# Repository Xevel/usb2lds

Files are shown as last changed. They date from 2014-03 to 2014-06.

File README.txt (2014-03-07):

USB2LDS
=======

2014 Nicolas "Xevel" Saugnier

Interface boards for the Neato LDS - the Lidar of the XV-11.
More on the Neato LDS : http://xv11hacking.wikispaces.com/LIDAR+Sensor

Boards:
- USB2LDS: USB interface for the Neato LDS, that also takes care of the motor control.
- Neato LDS Breakout Board (or NLDSBB): Simple breakout board that exposes the UART of the LDS, but takes care of the motor control.

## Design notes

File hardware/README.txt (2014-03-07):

USB2LDS hardware
================

USB2LDS versions:

v2.0 - 2014/01/12
- replaced FTDI with Atmega32u2
- added mosfet to allow PWM control of the motor
- added debug and hacking pads (/RST, /HWB, and the whole SPI bus)

v1.1 - 2014/01/11
- corrected LDS_TX/LDS_RX inversion on the connector
- The Lidar needs more power, use 3.3V regulator power instead of 3V3OUT from the FT232RL

V1.0 - 2014/01/09
- inital release

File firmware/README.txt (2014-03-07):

USB2LDS firmware
================

nlds - library to read data from the LDS (Firmware v2.4 and above) an extract the turn rate information.

nldsbb - firmware for the Neato LDS Breakout Board (ATtiny2313A)

usb2lds - firmware for the USB2LDS (ATmega32u2)

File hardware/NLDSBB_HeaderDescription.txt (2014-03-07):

Header of FTDI cable, interpreted from FTDI side.
GND: common ground
CTS: doit etre mise a GND par la cible
VCC: fournit 5V a la cible
TXD: envoi des char à la cible, doit être connecté au RXI de la cible
RXD: recoi les char de la cible, doit être connecté au TXO de la cible
RTS: output qui dit quand le FTDI est pret a recevoir. Laissé non connecté du coté cible si elle n'est pas capable de réguler son flux.

Header, from the board perspective:
GND : common ground
/MOT: connected to CTS, it can be controlled by the host to turn the motor ON (LOW or not connected) or OFF (HIGH)
VIN : power input, 5V
RXI : RX Input, goes directly to the LDS. This can be used by the host to send commands to the LDS, preferably when the motor is stopped.
TXO : TX output, comes directly from the LDS. That's where the info from the sensor will be avaialable for the host to read.
NC  : not connected

Only GND, VIN and TXO are necessary to read the info from the LDS.

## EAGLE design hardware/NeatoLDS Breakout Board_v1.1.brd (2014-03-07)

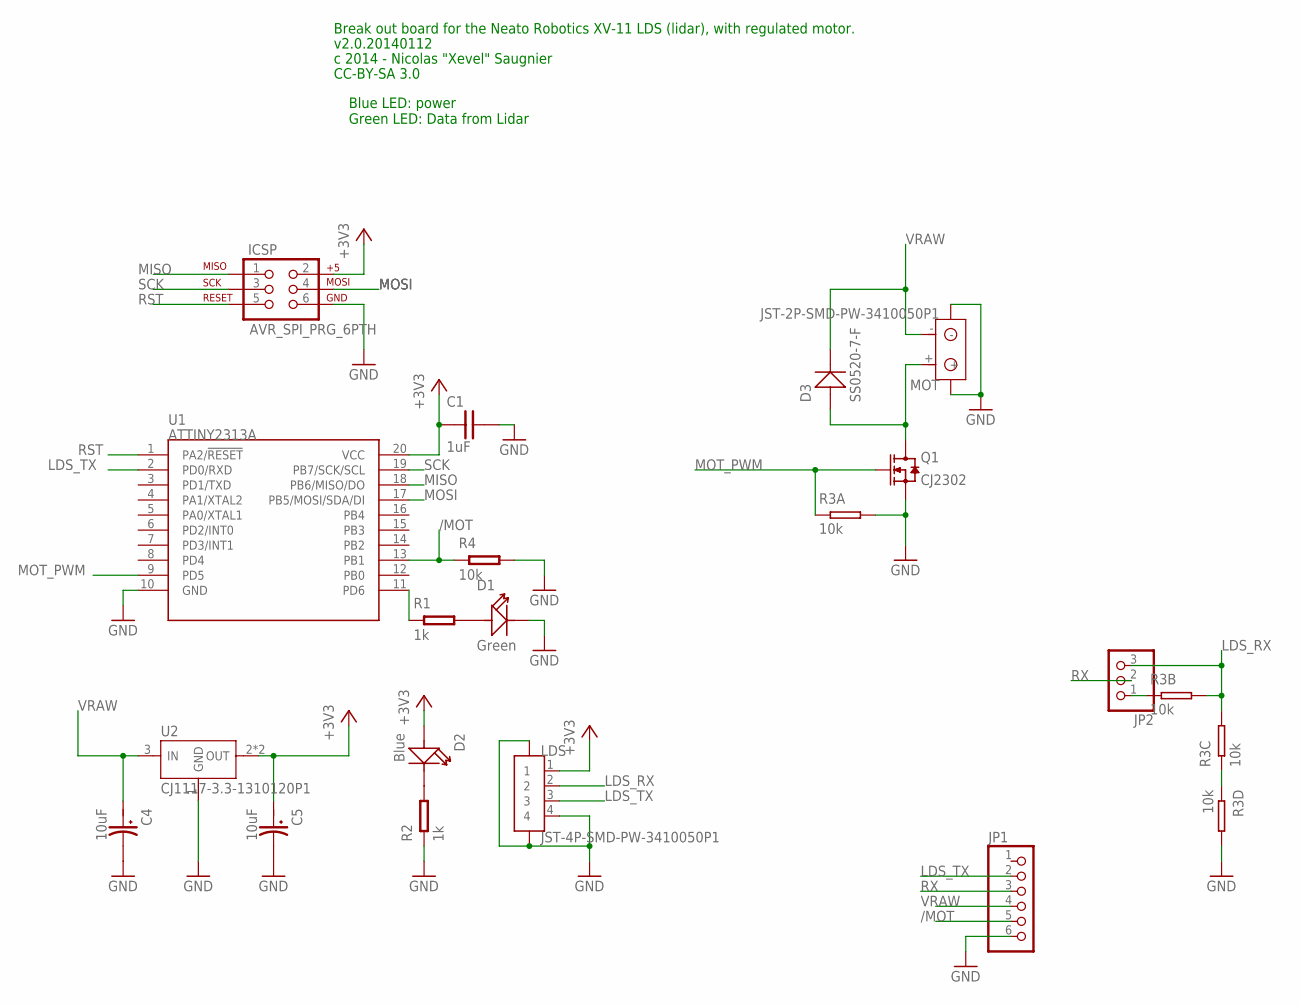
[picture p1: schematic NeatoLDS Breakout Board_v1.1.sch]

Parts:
C1: 1uF; C0603
C4, C5: 10uF; AVX-A
D1: Green; LED0603
D2: Blue; LED0603
D3: SS0520-7-F; SOD123
ICSP: AVR_SPI_PRG_6PTH; 2X3
JP1: PINHD-1X6; 1X06
JP2: PINHD-1X3; 1X03
LDS: JST-4P-SMD-PW-3410050P1; CON-4P-SMD-2.0-90D
MOT: JST-2P-SMD-PW-3410050P1; 2P-SMD-2.0-90D
Q1: CJ2302; SOT23
R1, R2: 1k; R0603
R3: 10k; R1206-8
R4: 10k; R0603
U1: ATTINY2313A; SOP20W
U2: CJ1117-3.3-1310120P1; SOT89

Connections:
+3V3: C1.1, C5.+ (1), D2.+, ICSP.2, LDS.1, U1.20 (VCC), U2.2 (OUT), U2.4 (OUT)
/MOT: JP1.5, R4.1, U1.13 (PB1)
GND: C1.2, C4.- (2), C5.- (2), D1.-, ICSP.6, JP1.6, LDS.4, LDS.5, LDS.6, MOT.3, MOT.4, Q1.2 (S), R2.1, R3.5 (2), R3.8 (2), R4.2, U1.10 (GND), U2.1 (GND)
LDS_RX: JP2.3, LDS.2, R3.6 (2), R3.7 (2)
LDS_TX: JP1.2, LDS.3, U1.2 (PD0/RXD)
MISO: ICSP.1, U1.18 (PB6/MISO/DO)
MOSI: ICSP.4, U1.17 (PB5/MOSI/SDA/DI)
MOT_PWM: Q1.1 (G), R3.1, U1.9 (PD5)
unnamed: R3.3 (1), R3.4 (1)
unnamed: JP2.1, R3.2 (1)
unnamed: R1.1, U1.11 (PD6)
unnamed: D3.+, MOT.+, Q1.3 (D)
unnamed: D1.+, R1.2
unnamed: D2.-, R2.2
RST: ICSP.5, U1.1 (PA2/!RESET)
RX: JP1.3, JP2.2
SCK: ICSP.3, U1.19 (PB7/SCK/SCL)
VRAW: C4.+ (1), D3.-, JP1.4, MOT.-, U2.3 (IN)

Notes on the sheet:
Blue LED: power Green LED: Data from Lidar
Break out board for the Neato Robotics XV-11 LDS (lidar), with regulated motor.
c 2014 - Nicolas "Xevel" Saugnier
CC-BY-SA 3.0
v2.0.20140112

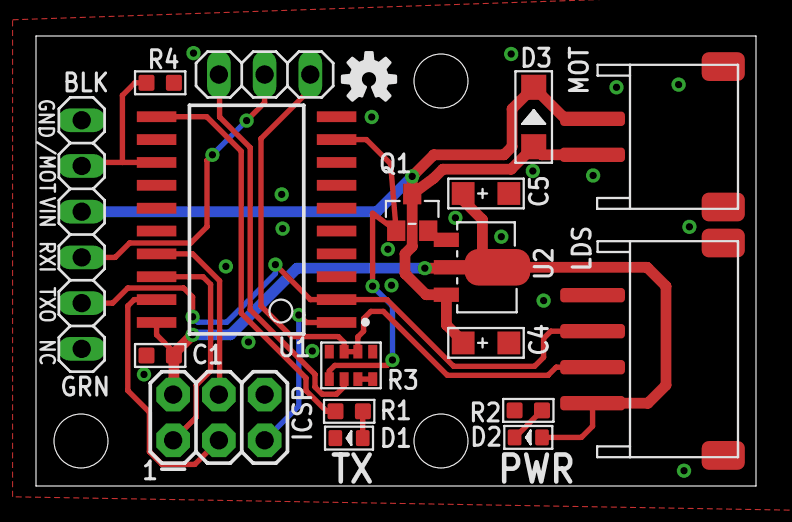
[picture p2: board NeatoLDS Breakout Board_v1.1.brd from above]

Board: 2 copper layers, 40.0 x 25.0 mm, 20 parts (1 on the bottom side), 18 nets.

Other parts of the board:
U$1, U$2: OSHW-LOGO-S

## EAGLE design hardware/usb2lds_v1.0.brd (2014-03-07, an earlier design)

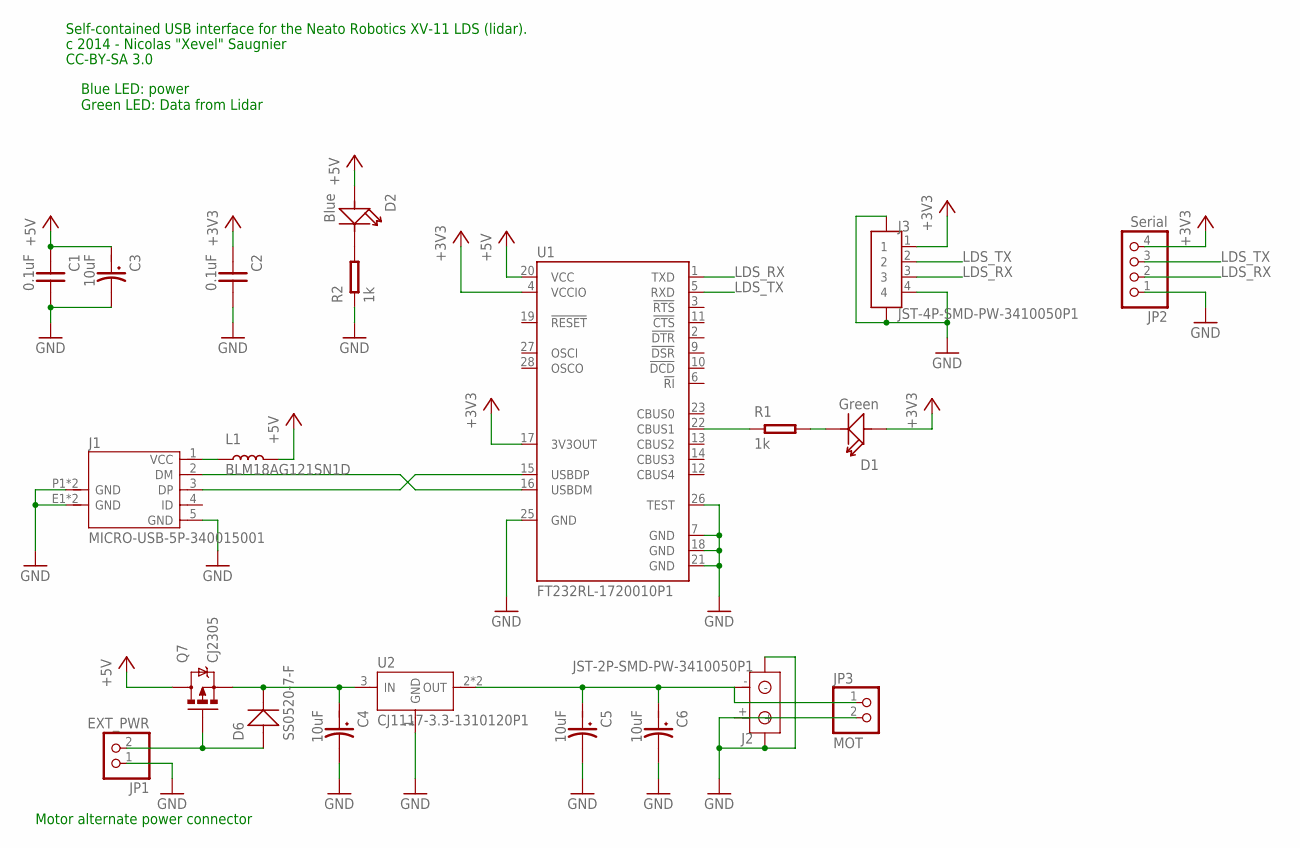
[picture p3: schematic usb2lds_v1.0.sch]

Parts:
C1, C2: 0.1uF; C0603
C3, C4, C5, C6: 10uF; AVX-A
D1: Green; LED0603
D2: Blue; LED0603
D6: SS0520-7-F; SOD123
J1: MICRO-USB-5P-340015001; B-SMD-5P
J2: JST-2P-SMD-PW-3410050P1; 2P-SMD-2.0-90D
J3: JST-4P-SMD-PW-3410050P1; CON-4P-SMD-2.0-90D
JP1: EXT_PWR; 1X02
JP2: Serial; 1X04
JP3: MOT; 1X02
L1: BLM18AG121SN1D; L0603
Q7: CJ2305; SOT-23-3_N/SSOT-3_N
R1, R2: 1k; R0603
U1: FT232RL-1720010P1; SSOP28
U2: CJ1117-3.3-1310120P1; SOT89

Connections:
+3V3: C2.1, D1.+, J3.1, JP2.4, U1.4 (VCCIO), U1.17 (3V3OUT)
+5V: C1.1, C3.+ (1), D2.+, L1.2, Q7.3 (D), U1.20 (VCC)
GND: C1.2, C2.2, C3.- (2), C4.- (2), C5.- (2), C6.- (2), J1.5 (GND), J1.E1 (GND), J1.E2 (GND), J1.P1 (GND), J1.P2 (GND), J2.3, J2.4, J2.+, J3.4, J3.5, J3.6, JP1.1, JP2.1, JP3.2, R2.1, U1.7 (GND), U1.18 (GND), U1.21 (GND), U1.25 (GND), U1.26 (TEST), U2.1 (GND)
LDS_RX: J3.3, JP2.2, U1.1 (TXD)
LDS_TX: J3.2, JP2.3, U1.5 (RXD)
unnamed: J1.2 (DM), U1.16 (USBDM)
unnamed: J1.3 (DP), U1.15 (USBDP)
unnamed: J1.1 (VCC), L1.1
unnamed: D1.-, R1.2
unnamed: D2.-, R2.2
unnamed: R1.1, U1.22 (CBUS1)
unnamed: C5.+ (1), C6.+ (1), J2.-, JP3.1, U2.2 (OUT), U2.4 (OUT)
unnamed: C4.+ (1), D6.-, Q7.2 (S), U2.3 (IN)
VUSB: D6.+, JP1.2, Q7.1 (G)

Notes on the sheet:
Blue LED: power Green LED: Data from Lidar
Self-contained USB interface for the Neato Robotics XV-11 LDS (lidar).
c 2014 - Nicolas "Xevel" Saugnier
CC-BY-SA 3.0
Motor alternate power connector

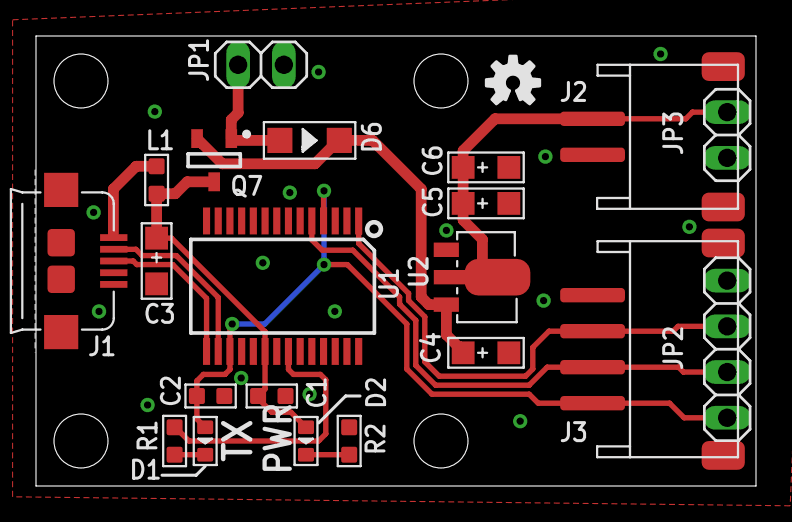
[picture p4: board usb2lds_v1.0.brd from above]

Board: 2 copper layers, 40.0 x 25.0 mm, 23 parts (1 on the bottom side), 14 nets.

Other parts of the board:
U$1, U$2: OSHW-LOGO-S

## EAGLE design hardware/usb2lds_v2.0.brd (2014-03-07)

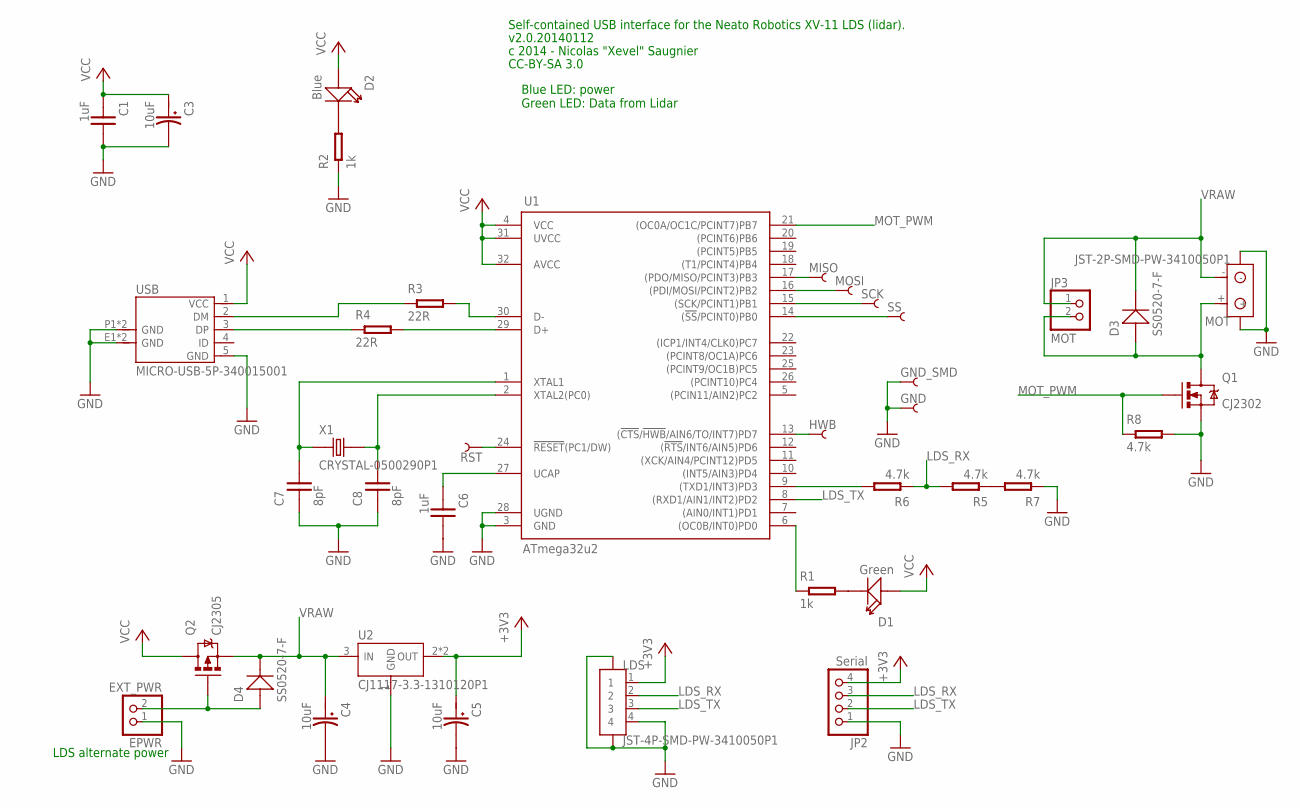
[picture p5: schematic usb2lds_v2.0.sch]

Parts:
C1, C6: 1uF; C0603
C3, C4, C5: 10uF; AVX-A
C7, C8: 8pF; C0603
D1: Green; LED0603
D2: Blue; LED0603
D3, D4: SS0520-7-F; SOD123
EPWR: EXT_PWR; 1X02
GND: PIN_SMD_2X2.5
GND_SMD: PIN_SMD_2X2.5
HWB: PIN_SMD_2X2.5
JP2: Serial; 1X04
JP3: MOT; 1X02
LDS: JST-4P-SMD-PW-3410050P1; CON-4P-SMD-2.0-90D
MISO: PIN_SMD_2X2.5
MOSI: PIN_SMD_2X2.5
MOT: JST-2P-SMD-PW-3410050P1; 2P-SMD-2.0-90D
Q1: CJ2302; SOT-23-3_N/SSOT-3_N
Q2: CJ2305; SOT-23-3_N/SSOT-3_N
R1, R2: 1k; R0603
R3, R4: 22R; R0603
R5, R6, R7, R8: 4.7k; R0603
RST: PIN_SMD_2X2.5
SCK: PIN_SMD_2X2.5
SS: PIN_SMD_2X2.5
U1: ATmega32u2; QFN-32_50P_L_MOD
U2: CJ1117-3.3-1310120P1; SOT89
USB: MICRO-USB-5P-340015001; B-SMD-5P
X1: CRYSTAL-0500290P1; 2P-SMD-5.0X3.2

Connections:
+3V3: C5.+ (1), JP2.4, LDS.1, U2.2 (OUT), U2.4 (OUT)
GND: C1.2, C3.- (2), C4.- (2), C5.- (2), C6.2, C7.1, C8.1, EPWR.1, GND.PIN, GND_SMD.PIN, JP2.1, LDS.4, LDS.5, LDS.6, MOT.3, MOT.4, Q1.2 (S), R2.1, R7.1, R8.2, U1.3 (GND), U1.28 (UGND), U2.1 (GND), USB.5 (GND), USB.E1 (GND), USB.E2 (GND), USB.P1 (GND), USB.P2 (GND)
HWB: HWB.PIN, U1.13 ((!CTS!/!HWB!/AIN6/TO/INT7)PD7)
LDS_RX: JP2.3, LDS.2, R5.2, R6.1
LDS_TX: JP2.2, LDS.3, U1.8 ((RXD1/AIN1/INT2)PD2)
MOT_PWM: Q1.1 (G), R8.1, U1.21 ((OC0A/OC1C/PCINT7)PB7)
unnamed: R6.2, U1.9 ((TXD1/INT3)PD3)
unnamed: R1.1, U1.6 ((OC0B/INT0)PD0)
unnamed: C6.1, U1.27 (UCAP)
unnamed: D3.+, JP3.2, MOT.+, Q1.3 (D)
unnamed: C8.2, U1.2 (XTAL2(PC0)), X1.2
unnamed: D1.-, R1.2
unnamed: D2.-, R2.2
unnamed: C7.2, U1.1 (XTAL1), X1.1
unnamed: R5.1, R7.2
unnamed: R3.2, U1.30 (D-)
unnamed: R4.2, U1.29 (D+)
unnamed: R3.1, USB.2 (DM)
unnamed: R4.1, USB.3 (DP)
unnamed: MISO.PIN, U1.17 ((PDO/MISO/PCINT3)PB3)
unnamed: MOSI.PIN, U1.16 ((PDI/MOSI/PCINT2)PB2)
unnamed: SCK.PIN, U1.15 ((SCK/PCINT1)PB1)
unnamed: SS.PIN, U1.14 ((!SS!/PCINT0)PB0)
RST: RST.PIN, U1.24 (!RESET!(PC1/DW))
VCC: C1.1, C3.+ (1), D1.+, D2.+, Q2.3 (D), U1.4 (VCC), U1.31 (UVCC), U1.32 (AVCC), USB.1 (VCC)
VRAW: C4.+ (1), D3.-, D4.-, JP3.1, MOT.-, Q2.2 (S), U2.3 (IN)
VUSB: D4.+, EPWR.2, Q2.1 (G)

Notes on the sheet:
Blue LED: power Green LED: Data from Lidar
Self-contained USB interface for the Neato Robotics XV-11 LDS (lidar).
c 2014 - Nicolas "Xevel" Saugnier
CC-BY-SA 3.0
LDS alternate power
v2.0.20140112

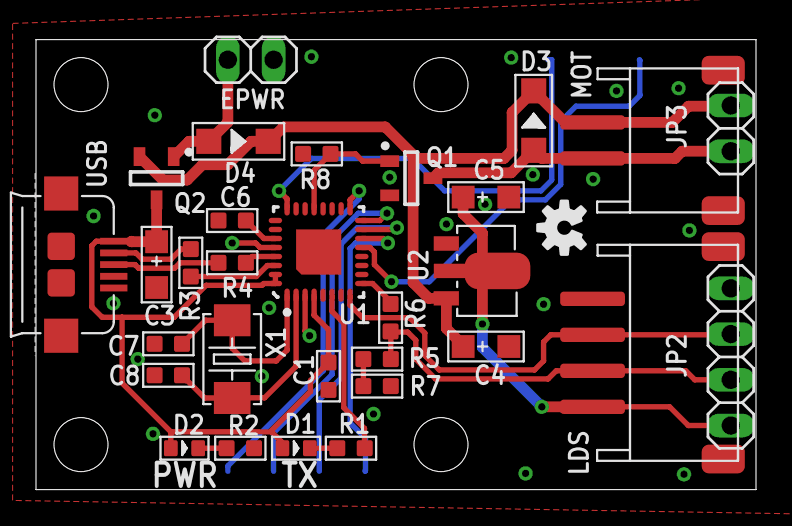
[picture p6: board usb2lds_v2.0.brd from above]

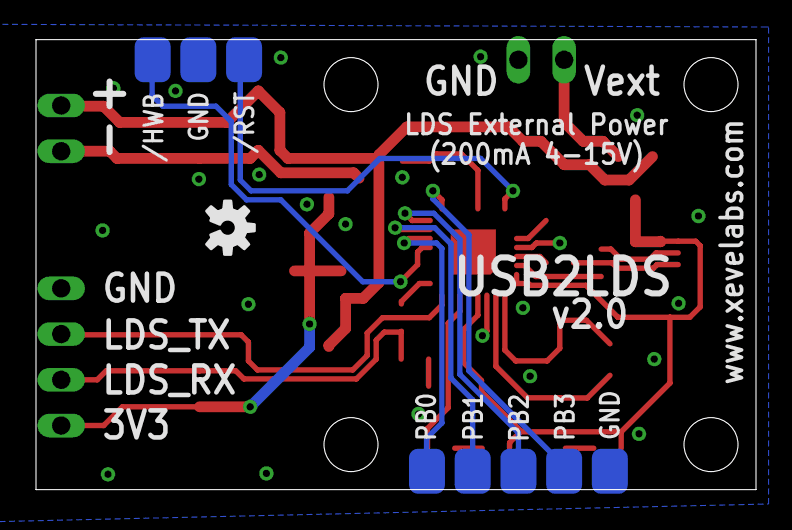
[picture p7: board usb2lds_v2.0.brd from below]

Board: 2 copper layers, 40.0 x 25.0 mm, 40 parts (9 on the bottom side), 27 nets.

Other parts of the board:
U$1, U$2: OSHW-LOGO-S

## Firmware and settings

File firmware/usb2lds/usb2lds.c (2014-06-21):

/*
    usb2lds.c

    Copyright 2014 - Nicolas "Xevel" Saugnier

    Based on:
    - LUFA library, by Dean Camera
    - USB2AX, By Nicolas Saugnier and Richard Ibbotson  
*/
/*
  Original notice:

  Copyright 2013  Dean Camera (dean [at] fourwalledcubicle [dot] com)

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
  The author disclaims all warranties with regard to this
  software, including all implied warranties of merchantability
  and fitness.  In no event shall the author be liable for any
  special, indirect or consequential damages or any damages
  whatsoever resulting from loss of use, data or profits, whether
  in an action of contract, negligence or other tortious action,
  arising out of or in connection with the use or performance of
  this software.
*/

/** \file
 *
 *  Main source file for the usb2lds firmware. It does the hardware initialization, reads data from one end and sends it to the other.
 */

#include "usb2lds.h"
#include "reset.h"
#include <nlds/nlds.h>
#include "time.h"

// Pin wired:
//   USART RX   (PD2/RXD1)
//   USART TX   (PD3/TXD1)
//   MOT PWM    (PB7/OC0A) inverted logic
//   TX LED     (PD0)
//   MISO       PB3
//   MOSI       PB2
//   SCK        PB1
//   !SS        PB0


USB_ClassInfo_CDC_Device_t VirtualSerial_CDC_Interface =
	{
		.Config =
			{
				.ControlInterfaceNumber   = 0,
				.DataINEndpoint           =
					{
						.Address          = CDC_TX_EPADDR,
						.Size             = CDC_TXRX_EPSIZE,
						.Banks            = 1,
					},
				.DataOUTEndpoint =
					{
						.Address          = CDC_RX_EPADDR,
						.Size             = CDC_TXRX_EPSIZE,
						.Banks            = 1,
					},
				.NotificationEndpoint =
					{
						.Address          = CDC_NOTIFICATION_EPADDR,
						.Size             = CDC_NOTIFICATION_EPSIZE,
						.Banks            = 1,
					},
			},
	};

static FILE USBSerialStream;

static RingBuffer_t USBtoUSART_Buffer;
static uint8_t      USBtoUSART_Buffer_Data[128];
static RingBuffer_t USARTtoUSB_Buffer;
static uint8_t      USARTtoUSB_Buffer_Data[128];

uint8_t needs_bootload = false; // In EVENT_CDC_Device_LineEncodingChanged, this flag is set when the baudrate is at a pre-defined value
uint8_t setup_mode;
uint8_t display_mode;

#define DISPLAY_NONE 0
#define DISPLAY_GRAPH 1
#define DISPLAY_VALUES 2

uint16_t rpm;
uint16_t last_rpm;
uint8_t has_new_rpm_value;
uint8_t mot_should_run;
uint32_t last_rpm_timestamp;

int16_t rpm_setpoint; //speed is expressed in 64th of rpm (6 bit shift) and we want it to turn at 300 rpm (= 5 rotation/s)
uint8_t motor_pwm;

uint8_t feedforward_fixed;
double feedforward_coeff;
uint8_t feedforward_mode;

#define FEEDFORWARD_NONE            (0)
#define FEEDFORWARD_FIXED           (1)
#define FEEDFORWARD_PROPORTIONAL    (2)

double Kp;
double Ki;
double Kd;
double err_acc;
double last_err;
double delta;

// assign 4 byte for each, even the ones that are smaller than that in case we want to change their size later without having to chang all the other ones.
#define EE_ADDR_KP          (   (float*)32)
#define EE_ADDR_KI          (   (float*)36)
#define EE_ADDR_KD          (   (float*)40)
#define EE_ADDR_SETPOINT    ((uint16_t*)44)
#define EE_ADDR_DELTA       (   (float*)48)
#define EE_ADDR_FF_MODE     ( (uint8_t*)52)
#define EE_ADDR_FF_FIXED    ( (uint8_t*)56)
#define EE_ADDR_FF_COEFF    (   (float*)60)
#define EE_ADDR_MAGIC       ((uint32_t*)64)
uint32_t eeprom_magic_value = 0xbadbeef;

void save_eeprom(){
    eeprom_update_float(EE_ADDR_KP, Kp);
    eeprom_update_float(EE_ADDR_KI, Ki);
    eeprom_update_float(EE_ADDR_KD, Kd);
    eeprom_update_word(EE_ADDR_SETPOINT, rpm_setpoint);
    eeprom_update_float(EE_ADDR_DELTA, delta);
    eeprom_update_byte(EE_ADDR_FF_MODE, feedforward_mode);
    eeprom_update_byte(EE_ADDR_FF_FIXED, feedforward_fixed);
    eeprom_update_float(EE_ADDR_FF_COEFF, feedforward_coeff);
    eeprom_update_dword(EE_ADDR_MAGIC, eeprom_magic_value);
}

void load_default(){
    Kp = 0.05;
    Ki = 0.0001;
    Kd = 0.0001;
    rpm_setpoint = 19200; // = 300rpm * 64
    delta = 1.0;
    feedforward_fixed = 190;
    feedforward_coeff = 100.0;
    feedforward_mode = FEEDFORWARD_PROPORTIONAL;
}

void load_eeprom(){
    Kp = eeprom_read_float(EE_ADDR_KP);
    Ki = eeprom_read_float(EE_ADDR_KI);
    Kd = eeprom_read_float(EE_ADDR_KD);
    rpm_setpoint = eeprom_read_word(EE_ADDR_SETPOINT);
    delta = eeprom_read_float(EE_ADDR_DELTA);
    feedforward_fixed = eeprom_read_byte(EE_ADDR_FF_FIXED);
    feedforward_coeff = eeprom_read_float(EE_ADDR_FF_COEFF);
    feedforward_mode = eeprom_read_byte(EE_ADDR_FF_MODE);
}

void show_pid(){    
    fprintf(&USBSerialStream, "Setpoint=%u (%.2frpm, %.2frps)\r\nKp=%.5f, Ki=%.5f, Kd=%.5f [delta=%.5f]\r\n",
        rpm_setpoint,
        (double)rpm_setpoint/64,
        (double)rpm_setpoint/3840,
        Kp, Ki, Kd,
        delta);
}


void show_display(){
    switch (display_mode)
    {
        case DISPLAY_VALUES:
            fprintf(&USBSerialStream, "Display Values [rpm, error, output before clamping]\r\n");
            break;
        case DISPLAY_GRAPH:
            fprintf(&USBSerialStream, "Display Graph (not implemented yet)\r\n");
            break;
        default:
            fprintf(&USBSerialStream, "Display None\r\n");
            break;
    }

}

void show_feedforward(){
    fprintf(&USBSerialStream, "Feedforward fixed = %u\r\n", feedforward_fixed);
    fprintf(&USBSerialStream, "Feedforward proportional = %u/%.2f = %.2f\r\n", rpm_setpoint, feedforward_coeff, (double)rpm_setpoint/feedforward_coeff);
    fprintf(&USBSerialStream, "Feedforward current mode: ");
    switch (feedforward_mode)
    {
        case FEEDFORWARD_FIXED:
            fprintf(&USBSerialStream, "FIXED\r\n");
            break;
        case FEEDFORWARD_PROPORTIONAL:
            fprintf(&USBSerialStream, "PROPORTIONAL\r\n");
            break;
        default:
            fprintf(&USBSerialStream, "NONE\r\n");
            break;
    }
}

void show_motor(){
    if (mot_should_run){
        fprintf(&USBSerialStream, "Motor ON\r\n");
    } else {
        fprintf(&USBSerialStream, "Motor OFF\r\n");
    }
}

void eeprom_init(){
    if (eeprom_read_dword(EE_ADDR_MAGIC) != eeprom_magic_value){
        load_default();
    } else {
        load_eeprom();
    }
}

int main(void)
{
	SetupHardware();
    eeprom_init();
    motor_pwm = 190;

    RingBuffer_InitBuffer(&USBtoUSART_Buffer, USBtoUSART_Buffer_Data, sizeof(USBtoUSART_Buffer_Data));
    RingBuffer_InitBuffer(&USARTtoUSB_Buffer, USARTtoUSB_Buffer_Data, sizeof(USARTtoUSB_Buffer_Data));

	// Create a regular character stream for the interface so that it can be used with the stdio.h functions
	CDC_Device_CreateStream(&VirtualSerial_CDC_Interface, &USBSerialStream);

	GlobalInterruptEnable();

	for (;;)
	{
        if (setup_mode){
            int16_t c = CDC_Device_ReceiveByte(&VirtualSerial_CDC_Interface);
            if (!(c < 0)){
                switch(c){
                    case 'L': // reset
                        fprintf(&USBSerialStream, "Load default values\r\n");
                        load_default();
                    case 'a':
                        show_pid();
                        show_feedforward();
                        show_motor();
                        show_display();
                        break;
                    //PID coef adjust
                    case 'p':
                        Kp -= delta;
                        if (Kp < 0){
                            Kp = 0;
                        }
                        show_pid();
                        break;
                    case 'P':
                        Kp += delta;
                        show_pid();
                        break;
                    case 'i':
                        Ki -= delta;
                        if (Ki < 0){
                            Ki = 0;
                        }
                        show_pid();
                        break;
                    case 'I':
                        Ki += delta;
                        show_pid();
                        break;
                    case 'd':
                        Kd -= delta;
                        if (Kd < 0){
                            Kd = 0;
                        }
                        show_pid();
                        break;
                    case 'D':
                        Kd += delta;
                        show_pid();
                        break;
                    case '+':
                        delta *= 10.0;
                        show_pid();
                        break;
                    case '-':
                        delta /= 10.0;
                        show_pid();
                        break;
                    case 'r':
                        rpm_setpoint -= 64;
                        show_pid();
                        break;
                    case 'R':
                        rpm_setpoint += 64;
                        show_pid();
                        break;

                    case '0':
                        feedforward_mode = FEEDFORWARD_NONE;
                        show_feedforward();
                        break;
                    case '1':
                        feedforward_mode = FEEDFORWARD_FIXED;
                        show_feedforward();
                        break;
                    case '2':
                        feedforward_mode = FEEDFORWARD_PROPORTIONAL;
                        show_feedforward();
                        break;
                        
                    case 'f':
                        feedforward_fixed -= 1;
                        show_feedforward();
                        break;
                    case 'F':
                        feedforward_fixed += 1;
                        show_feedforward();
                        break;

                    case 'c':
                        feedforward_coeff -= delta;
                        show_feedforward();
                        break;
                    case 'C':
                        feedforward_coeff += delta;
                        show_feedforward();
                        break;

                    case 's': // save
                        save_eeprom();
                        fprintf(&USBSerialStream, "Values saved to EEPROM\r\n");
                        break;
                    
                    case 'm':
                        mot_should_run = 0;
                        show_motor();
                        break;
                    case 'M':
                        mot_should_run = 1;
                        show_motor();
                        break;
                    case 'g':
                        display_mode = DISPLAY_NONE;
                        show_display();
                        break;
                    case 'G':
                        display_mode = DISPLAY_GRAPH;
                        show_display();
                        break;
                    case 'v':
                        display_mode = DISPLAY_VALUES;
                        show_display();
                        break;


                    case ' ': // to make the motor spin whatever the computations
                        motor_pwm = 200;
                        break;
                }
            }


        } else {
            //Copy data from USB to the LDS buffer, if there is room.
            if (!(RingBuffer_IsFull(&USBtoUSART_Buffer)))
            {
                int16_t ReceivedByte = CDC_Device_ReceiveByte(&VirtualSerial_CDC_Interface);
                if (!(ReceivedByte < 0)){
                    RingBuffer_Insert(&USBtoUSART_Buffer, ReceivedByte);
                }
            }

            //Send data from the LDS to USB
            uint16_t BufferCount = RingBuffer_GetCount(&USARTtoUSB_Buffer);
            if (BufferCount)
            {
                Endpoint_SelectEndpoint(VirtualSerial_CDC_Interface.Config.DataINEndpoint.Address);

                if (Endpoint_IsINReady())
                {
                    // Never send more than one bank size less one byte to the host at a time, so that we don't block
                    // while a Zero Length Packet (ZLP) to terminate the transfer is sent if the host isn't listening
                    uint8_t BytesToSend = MIN(BufferCount, (CDC_TXRX_EPSIZE - 1));
                    while (BytesToSend--)
                    {
                        if (CDC_Device_SendByte(&VirtualSerial_CDC_Interface,
                        RingBuffer_Peek(&USARTtoUSB_Buffer)) != ENDPOINT_READYWAIT_NoError)
                        {
                            break;
                        }

                        // Dequeue the already sent byte from the buffer now we have confirmed that no transmission error occurred
                        RingBuffer_Remove(&USARTtoUSB_Buffer);
                    }
                }
            }
            
            // Load the next byte from the USART transmit buffer into the USART
            if (!(RingBuffer_IsEmpty(&USBtoUSART_Buffer))){
                Serial_SendByte(RingBuffer_Remove(&USBtoUSART_Buffer));
            }
        }
        
		
        uint16_t dt = 1; // init just to avoid potential warning

        cli();
        if (nlds_rpm_updated_get()){
            rpm = nlds_rpm_get();
            nlds_rpm_updated_clear();
            has_new_rpm_value = 1;
            dt = micros_reset();
        }
        sei();

        // tx_led_toggle(); // TODO flash the led when stuff happens
        
        // motor control
        if (has_new_rpm_value && rpm!=last_rpm){
            has_new_rpm_value = 0;
            double err = (double)rpm_setpoint - rpm;

            double fdt = (double)dt/1000.0; // get back to something closer to 1 to avoid orders of magnitude of difference in the coeffs
            
            err_acc += err;

            double output = Kp * err + Kd * (last_err-err)/fdt + Ki * err_acc*fdt;
            
            switch(feedforward_mode){
                case FEEDFORWARD_FIXED:
                    output += feedforward_fixed;
                    break;
                case FEEDFORWARD_PROPORTIONAL:
                    output += (double)rpm_setpoint / feedforward_coeff; 
                    break;
                case FEEDFORWARD_NONE:
                default:
                    break;
            }
            
            last_err = err;
            last_rpm = rpm;

            if (setup_mode){
                switch(display_mode){
                    case DISPLAY_GRAPH:
                        // display on 80 columns the output and setpoint

                        //TODO
                        
                        break;
                    case DISPLAY_VALUES:
                        fprintf(&USBSerialStream, "%u %f %f\r\n", rpm, err, output);
                        break;
                    case DISPLAY_NONE:
                    default:
                        break;

                }
            }

            if (output > 255){
                output = 255;
            } else if (output < 0){
                output = 0;
            }

            motor_pwm = (uint8_t) output;

        }
        if ( mot_should_run ){
            apply_motor_pwm(motor_pwm);
        } else {
            apply_motor_pwm(0);
        }

		CDC_Device_USBTask(&VirtualSerial_CDC_Interface);
		USB_USBTask();
	}
}


void usart_init(){ // Usart at 115200, 8N1
    cli();
    UCSR1A = (1<<U2X1); // x2
    UBRR1L = 16; // cf datasheet p175
    
    // enable TX, RX and RX interrupt
    UCSR1B =  (1<<RXCIE1) | (1 << RXEN1) | (1 << TXEN1); 
    sei();
}

void motor_init(){
    // Setup motor PWM (PD5/OC0B), inverting logic, phase correct (mode 1)
    TCCR0A = (1 << COM0A1) | (0 << COM0A0) | (0 << WGM01) | (1 << WGM00);
    TCCR0B = (0 << WGM02) | (1 << CS02) | (0 << CS01) | (0 << CS00);
    apply_motor_pwm(0);
    bitSet(DDRB, 7);
}

void apply_motor_pwm(uint8_t val){
    OCR0A = val;
}

void tx_led_init(){
    tx_led_off();
    bitSet(DDRD, 0);
}
void tx_led_on(){
    bitClear(PORTD, 0);
}
void tx_led_off(){
    bitSet(PORTD, 0);
}
void tx_led_toggle(){
    bitSet(PIND, 0);
}

void SetupHardware(void)
{
	// Disable watchdog if enabled by bootloader/fuses
	MCUSR &= ~(1 << WDRF);
	wdt_disable();

    clock_prescale_set(clock_div_1);

    micros_init();
    USB_Init();
    usart_init();
    tx_led_init();
    motor_init();
}


ISR(USART1_RX_vect)
{
    uint8_t c = UDR1;
    if (USB_DeviceState == DEVICE_STATE_Configured){
        RingBuffer_Insert(&USARTtoUSB_Buffer, c);
    }
    sei(); // once incoming data has been read, we can release the interrupts because nlds_parse should not be too long, and other timers need to be able to tick
    
    nlds_parse(c);
}


void EVENT_USB_Device_ConfigurationChanged(void)
{
	CDC_Device_ConfigureEndpoints(&VirtualSerial_CDC_Interface);
}

void EVENT_USB_Device_ControlRequest(void)
{
	CDC_Device_ProcessControlRequest(&VirtualSerial_CDC_Interface);
}

void EVENT_CDC_Device_LineEncodingChanged(USB_ClassInfo_CDC_Device_t* const CDCInterfaceInfo){
    // we don't allow changing the baud rate or any other details, things are already set up the right way to talk to the LDS.

    // If the baudrate is at this special (and unlikely) value, it means that we want to trigger the bootloader
    if (CDCInterfaceInfo->State.LineEncoding.BaudRateBPS == 1200){
        needs_bootload = true;
        setup_mode = true;
    } else if ( CDCInterfaceInfo->State.LineEncoding.BaudRateBPS == 9600 || CDCInterfaceInfo->State.LineEncoding.BaudRateBPS == 1337){
        setup_mode = true;
    } else {
        setup_mode = false;
    }   
}

// *********************  Soft reset/bootloader functionality *******************************************
// The bootloader can be ran by opening the serial port at 1200bps. Upon closing it, the reset process will be initiated
// and two seconds later, the board will re-enumerate as a DFU bootloader.

// adapted from http://www.avrfreaks.net/index.php?name=PNphpBB2&file=viewtopic&p=1008792#1008792
void EVENT_CDC_Device_ControLineStateChanged(USB_ClassInfo_CDC_Device_t* const CDCInterfaceInfo){
    static bool PreviousDTRState = false;
    bool        CurrentDTRState  = (CDCInterfaceInfo->State.ControlLineStates.HostToDevice & CDC_CONTROL_LINE_OUT_DTR);

    mot_should_run = CurrentDTRState;

    /* Check how the DTR line has been asserted */
    if (PreviousDTRState && !(CurrentDTRState) ){
        // PreviousDTRState == True AND CurrentDTRState == False
        // Host application has Disconnected from the COM port
        
        if (needs_bootload){
            apply_motor_pwm(0);
            Jump_To_Reset(true);
        }
    }
    PreviousDTRState = CurrentDTRState;
}
// ******************************************************************************************************

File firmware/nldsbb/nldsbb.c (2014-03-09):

/*
 * nldsbb.c
 *
 * Firmware for the Neato LDS Breakout Board
 *
 * Created: 19/02/2014 22:11:16
 *  Author: Xevel
 */ 

 #define F_CPU 16000000 // HACK 16MHz crystal instead of // 8MHz internal clock (CKDIV8 is deactivated)

#include <avr/io.h>
#include <avr/sfr_defs.h>
#include <avr/power.h>
#include <avr/wdt.h>
#include <avr/interrupt.h>
#include <util/delay.h>

#include <nlds/nlds.h>

#define bitSet(value, bit)       ((value) |= (1UL << (bit)))
#define bitClear(value, bit)     ((value) &= ~(1UL << (bit)))



#if DEBUG 
#define dbinit1     bitSet(DDRD , 2)
#define dbup1       bitSet(PORTD , 2)
#define dbdown1     bitClear(PORTD , 2)
#define dbtoggle1   bitSet(PIND , 2)
#else
#define dbinit1     
#define dbup1       
#define dbdown1     
#define dbtoggle1   
#endif

// Pin used:
//   USART RX (PD0/RXD)
//   MOT PWM (PD5/OC0B) inverted logic
//   TX LED (PD6)
//   /MOT (PB1)


void tx_led_on(){
    bitSet(PORTD, 6);
}
void tx_led_off(){
    bitClear(PORTD, 6);
}
void tx_led_toggle(){
    bitSet(PIND, 6);    
}

// PB1 is the /MOT input. Motor control is done only if this pin is set to LOW or left floating (it has a pull-down).
uint8_t mot_should_run(){
    return bit_is_clear(PORTB, 1);
}

uint16_t rpm;
uint8_t has_new_rpm_value;

void usart_setup(){ // Usart at 115200, 8N1
    cli();
    UCSRA = (1<<U2X); // x2
    UBRRL = 16; // cf attiny2313 datasheet p144
    UCSRB =  (1<<RXCIE) | (1 << RXEN) | (1 << TXEN);  // enable RX and its interrupt // TX for debug
    sei();
}

void usart_write(uint8_t data){ // for debug, the pin is left unconnected
    loop_until_bit_is_set(UCSRA, UDRE);
    UDR = data;
}

int16_t rpm_setpoint = 19200; //speed is expressed in 64th of rpm (6 bit shift) and we want it to turn at 300 rpm (= 5 rotation/s)
uint8_t motor_pwm = 200;

float Kp = 0.004;

void apply_motor_pwm(uint8_t val){
    OCR0B = val;
}


int main(void)
{
    // disable watchdog timer
    MCUSR &= ~(1 << WDRF);
    wdt_disable();

    dbinit1;
    dbdown1;

    // disable clock division : clock is now at the undivided 8MHz 
    clock_prescale_set(clock_div_1);

    // setup TX LED (PD6)
    bitSet(DDRD, 6);

    // Setup motor PWM (PD5/OC0B), inverting logic, phase correct (mode 1)
    TCCR0A = (1 << COM0B1) | (0 << COM0B0) | (0 << WGM01) | (1 << WGM00);
    TCCR0B = (0 << WGM02) | (1 << CS02) | (0 << CS01) | (0 << CS00);
    apply_motor_pwm(motor_pwm);
    bitSet(DDRD, 5);

    // Setup USART at 115200 bps, only RX
    usart_setup();
    sei();
    uint8_t nb_cnt = 0;
    while(1)
    {
        cli();
        if (nlds_rpm_updated_get()){
            rpm = nlds_rpm_get();
            nlds_rpm_updated_clear();
            has_new_rpm_value = 1;
            
            nb_cnt++;
            //dbup1;
            //dbdown1;
        }
        sei();


        // TODO fix the algorithm, it's currently an integral controller !!! 
        if (has_new_rpm_value && nb_cnt == 60){
            //usart_write(rpm >> 7);
            nb_cnt = 0;
            has_new_rpm_value = 0;
            int16_t err = rpm_setpoint - rpm; // error, in 64th of RPM
            
            float new_mot_pwm = (float)motor_pwm + Kp * err;

            //usart_write((int8_t)(err/128) );
            
            if (new_mot_pwm < 0){
                new_mot_pwm = 0;
            } else if (new_mot_pwm > 255){
                new_mot_pwm = 255;
            }
            motor_pwm = (uint8_t) new_mot_pwm;
            //usart_write((uint8_t)err);
            //usart_write((uint8_t)(err>>8));
        }
        
        if ( mot_should_run() ){
            apply_motor_pwm(motor_pwm);
        } else {
            apply_motor_pwm(0);
        }

    }
}

ISR(USART_RX_vect)
{
    uint8_t c = UDR;
    sei(); // once incoming data has been read, we can release the interrupts

    nlds_parse(c);
}

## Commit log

2014-03-07 Initial import, with USB2LDS boards, NLDSBB boards and preliminary code for the NLDSBB.
    [NeatoLDS Breakout Board_v0.1.brd, NeatoLDS Breakout Board_v0.1.sch, NeatoLDS Breakout Board_v1.0.brd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]
2014-03-07 Frankenstein-style usb2lds firmware, out of LUFA USBtoSerial, nldsbb and usb2ax. Not finished (motor control needed) and not tested at all.
2014-03-09 Added motor control and setup mode to tune the PID and more.
2014-03-09 Added a command to jumpstart the motor in case it has been stopped. Stopp the motor when going for a Reset.
    [usb2lds.c]
2014-06-21 Set better PID values by default. Added 9600 bps for the setup mode.

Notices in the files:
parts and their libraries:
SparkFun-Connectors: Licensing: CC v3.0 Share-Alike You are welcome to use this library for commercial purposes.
